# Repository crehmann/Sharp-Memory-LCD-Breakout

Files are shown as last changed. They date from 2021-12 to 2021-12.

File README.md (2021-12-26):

# Breakout Board for Sharp Memory Display (LS011B7DH03)

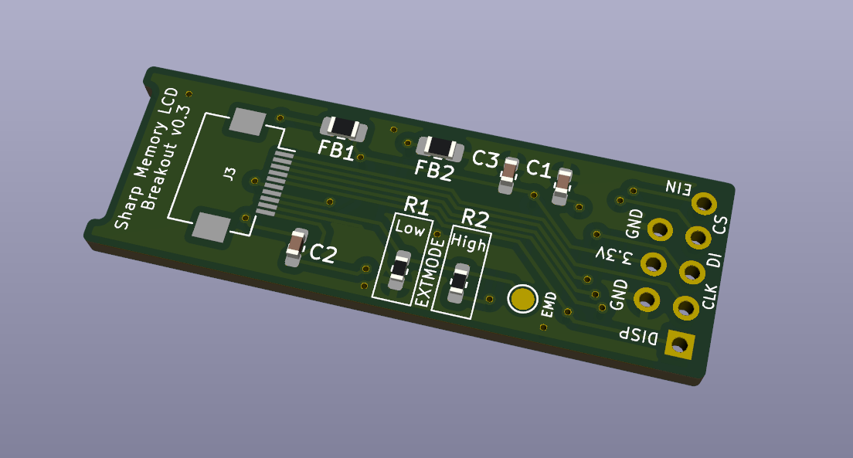
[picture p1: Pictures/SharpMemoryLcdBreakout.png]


## Bill of Material

| Name | Qty  | Package | Value | Description |
| --- | ---- | --- | --- | --- |
| FB1, FB2 | 2 | 0805 | 300mΩ DC Resistance, 600Ω impedance @ 100MHz | Ferrite Bead |
| C1 | 1 | 0603 | 560pF/680pF | Capacitor |
| C2, C3 | 2 | 0603 | 1uF | Capacitor |
| R1/R2 | 1 | 0603 | 10kΩ | Use either R1 **or** R2. Use R2 when VCOM toggling via EXTCOMIN pin (EIN) is used. |
| J3 | 1 | SMD | FH12-10S-0.5SH | FPC connector with 10 pins and 0.5mm pitch |
| LS011B7DH03 Display | 1 | - | | https://aliexpress.com/item/1005001809102193.html |

See the BOM csv file in the [release zip-file](https://github.com/crehmann/Sharp-Memory-LCD-Breakout/releases) for LCSC part numbers 

**Note:** The current revision v0.3 is **not** tested. v0.2 was using wrong capacitor values but the schematic worked otherwise ([see picture](https://raw.githubusercontent.com/crehmann/Sharp-Memory-LCD-Breakout/main/Pictures/displayOnBreakoutBoard.png)).

**Assembly**: Soldering by hand is doable. The pads for the components are larger for easier soldering. However, for the FPC connecter good equipment and routine is required as it has a pitch of only 0.5mm

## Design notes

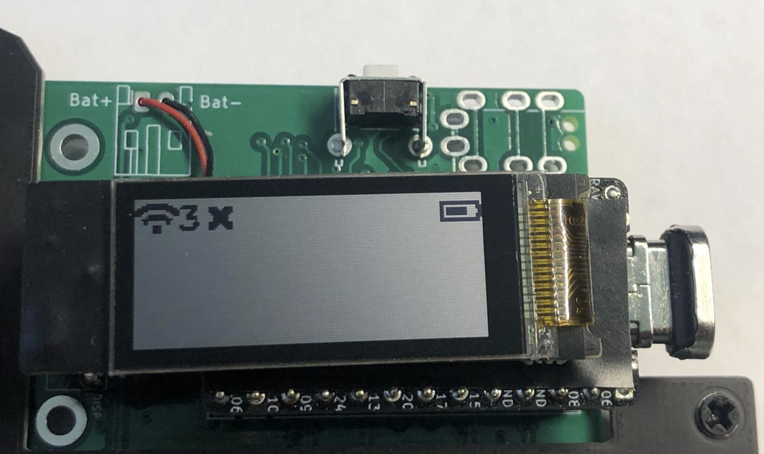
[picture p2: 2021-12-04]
Pictures/displayOnBreakoutBoard.png

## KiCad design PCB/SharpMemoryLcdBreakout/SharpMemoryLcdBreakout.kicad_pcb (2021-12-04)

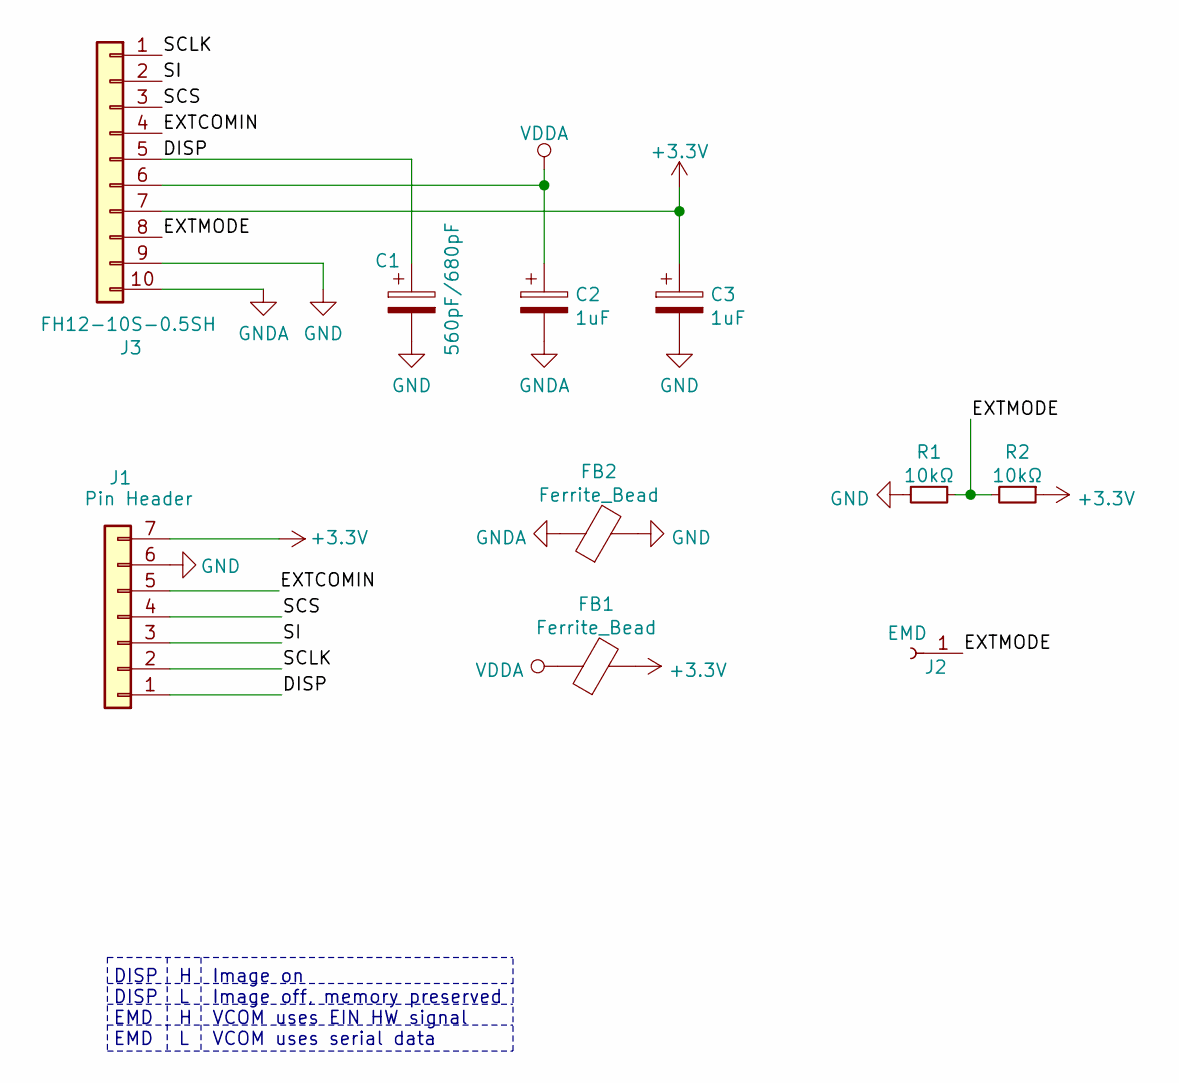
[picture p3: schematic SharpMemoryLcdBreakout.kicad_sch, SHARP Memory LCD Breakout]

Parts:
C1: 560pF/680pF; C_0603_1608Metric_Pad1.05x0.95mm_HandSolder; LCSC C1630
C2, C3: 1uF; C_0603_1608Metric_Pad1.05x0.95mm_HandSolder; LCSC C15849
FB1, FB2: Ferrite_Bead; R_0805_2012Metric_Pad1.15x1.40mm_HandSolder; LCSC C1017
J1: Pin Header; PinSocket_2Row_5+3_P2.54mm_Vertical
J2: EMD; TestPoint_Pad_D1.5mm
J3: FH12-10S-0.5SH; Hirose_FH12-10S-0.5SH_1x10-1MP_P0.50mm_Horizontal; LCSC C506791
R1, R2: 10kΩ; R_0603_1608Metric_Pad1.05x0.95mm_HandSolder; LCSC C25804

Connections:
+3V3: C3.1, FB1.2, J1.7, J3.7, R2.1
/DISP: C1.1, J1.1, J3.5
/EXTCOMIN: J1.5, J3.4
/EXTMODE: J2.1, J3.8, R1.1, R2.2
/SCLK: J1.2, J3.1
/SCS: J1.4, J3.3
/SI: J1.3, J3.2
GND: C1.2, C3.2, FB2.2, J1.6, J3.9, R1.2
GNDA: C2.2, FB2.1, J3.10
VDDA: C2.1, FB1.1, J3.6

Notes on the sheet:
DISP DISP EMD EMD
H L H L
Image on Image off, memory preserved VCOM uses EIN HW signal VCOM uses serial data

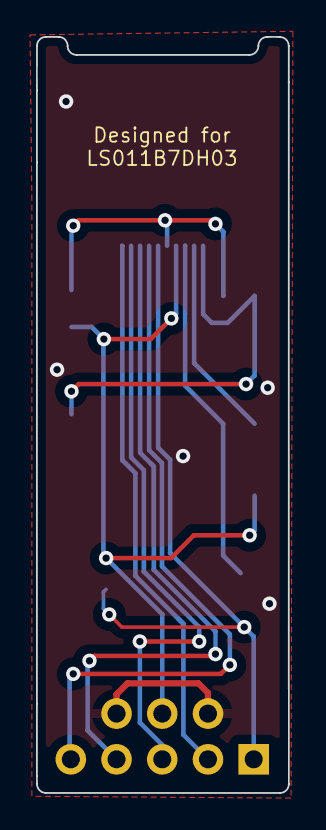
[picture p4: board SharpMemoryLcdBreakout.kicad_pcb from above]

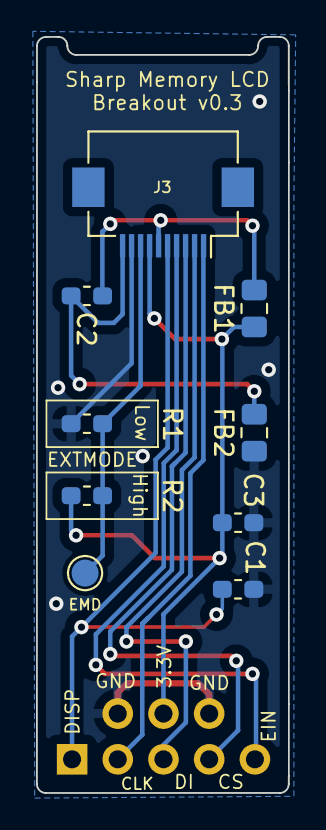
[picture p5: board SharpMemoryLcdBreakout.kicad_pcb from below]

Board: 2 copper layers, 14.0 x 42.0 mm, 10 parts (9 on the bottom side), 10 nets.

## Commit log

2021-10-20 Added project file with schematic and pcb design
    [SharpMemoryLcdBreakout.kicad_pcb, SharpMemoryLcdBreakout.kicad_sch]
2021-10-20 added mouse bite footprint
2021-10-20 increased size of pcb for smt assembly
    [SharpMemoryLcdBreakout.kicad_pcb, SharpMemoryLcdBreakout.kicad_sch]
2021-10-31 added pins for disp and emd
    [SharpMemoryLcdBreakout.kicad_pcb, SharpMemoryLcdBreakout.kicad_sch]
2021-11-06 switched EIN and EMD pin connections
    [SharpMemoryLcdBreakout.kicad_pcb, SharpMemoryLcdBreakout.kicad_sch]
2021-11-13 Mirrored FPC pins
    [SharpMemoryLcdBreakout.kicad_pcb, SharpMemoryLcdBreakout.kicad_sch]
2021-11-13 added panelized version
    [SharpMemoryLcdBreakout_PANELIZED.kicad_pcb]
2021-12-01 increased part size (0805) and improved silk screen and added ferrite beads
    [SharpMemoryLcdBreakout.kicad_pcb, SharpMemoryLcdBreakout.kicad_sch, SharpMemoryLcdBreakout_PANELIZED.kicad_pcb]
2021-12-04 Added BOM to readme and updated LCSC parts
    [SharpMemoryLcdBreakout-PANELIZED.kicad_pcb, SharpMemoryLcdBreakout.kicad_pcb, SharpMemoryLcdBreakout.kicad_sch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]
2021-12-04 added picture of working sample
2021-12-04 going back to 0603 for easier part selection
    [SharpMemoryLcdBreakout-PANELIZED.kicad_pcb, SharpMemoryLcdBreakout.kicad_pcb, SharpMemoryLcdBreakout.kicad_sch]
